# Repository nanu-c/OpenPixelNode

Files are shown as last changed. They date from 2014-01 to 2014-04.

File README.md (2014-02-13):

OpenPixelNode
=============

This project includes both hardware and software for an open-source LED controller for up to 4 ArtNet universes.

OpenPixelNode

More images here: http://flic.kr/s/aHsjQY2NrD

Hardware
--------
The hardware design is Arduino-compatible in terms of being based on an ATmega328 microcontroller running at 16MHz.
It uses the Wiznet Wiz820io addon board for Ethernet communication. There are voltage regulators for both 5V and 3.3V for the two logic circuits. This allows the board to be supplied with voltages of 5V to 30V.
There are 4 LED outputs with two digital ports each. This allows the board to control either SPI or single-wire LED strips.
At the moment there is only ICSP headers for programming.

Software
--------
The software is an Arduino sketch using a library for the ArtNet protocol and whatever LED communication protocol you may want to use. Please update the FastLED controller type to whatever LED you are using.

Dependencies
------------
[Arduino_ArtNet](https://github.com/media-architecture/Arduino_ArtNet)

[FastLED](https://github.com/media-architecture/FastLED)

[WIZ_Ethernet_Library](https://github.com/media-architecture/WIZ_Ethernet_Library)

[TrueRandom](https://code.google.com/p/tinkerit/wiki/TrueRandom)

Version history
---------------

### Prototype 2 (January 2014)
### Prototype 1 (September 2013)

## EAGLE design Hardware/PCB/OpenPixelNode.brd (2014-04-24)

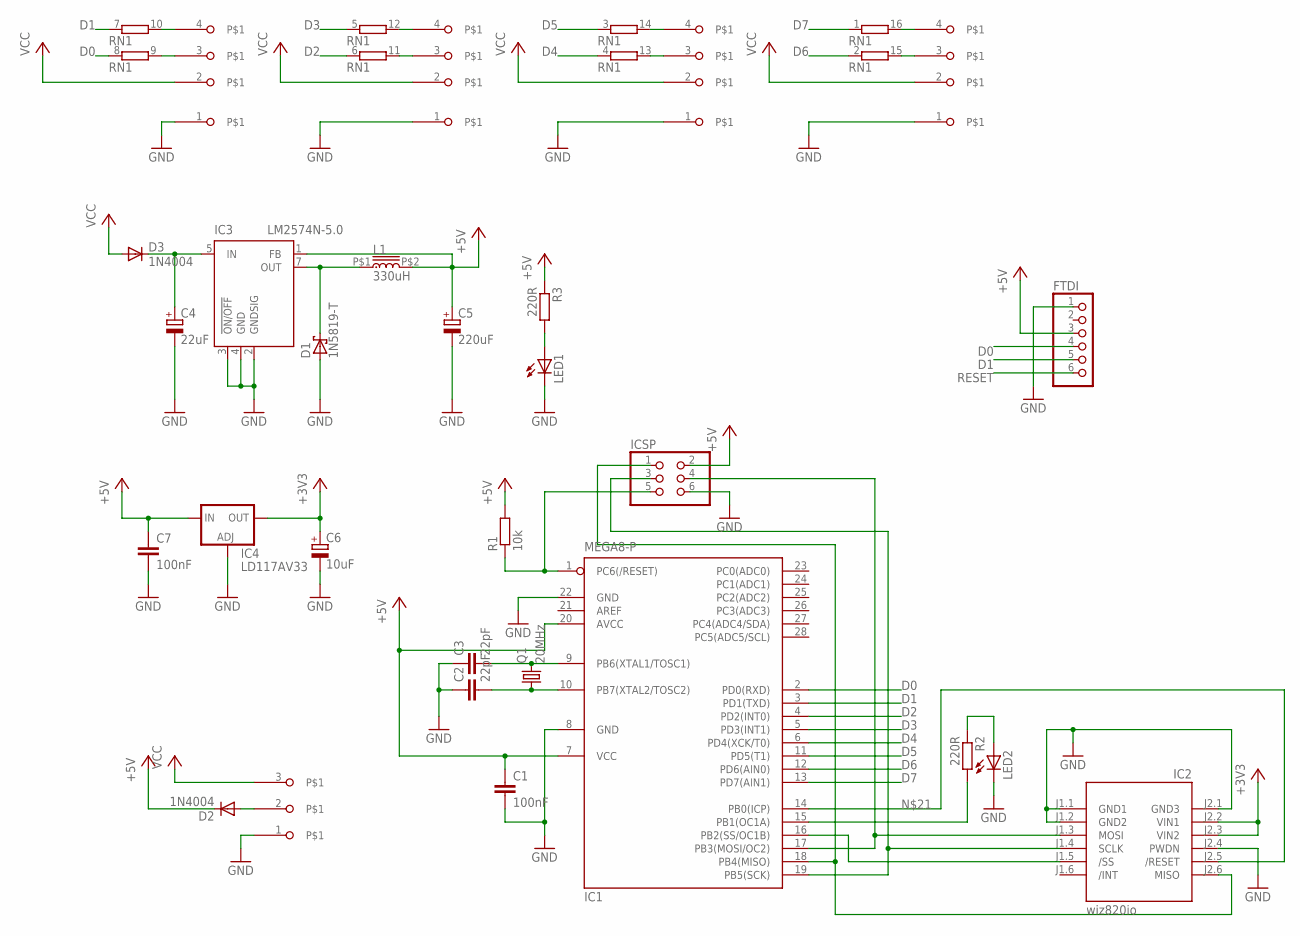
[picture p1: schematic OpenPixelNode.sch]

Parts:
C1, C7: 100nF; C025-025X050
C2, C3: 22pF; C025-025X050
C4: 22uF; E2,5-6
C5: 220uF; E2,5-6
C6: 10uF; E2,5-6
D1: 1N5819-T; DO41-7.6
D2, D3: 1N4004; DO41-10
FTDI: PINHD-1X6; 1X06
IC1: MEGA8-P; DIL28-3
IC2: wiz820io; WIZ820IO
IC3: LM2574N-5.0; DIL08
IC4: LD117AV33; TO220L1
ICSP: PINHD-2X3; 2X03
L1: 330uH; 13R334C
LED1, LED2: LED3MM
Q1: 20MHz; HC49/S
R1: 10k; 0207/10
R2, R3: 220R; 0207/10
RN1: 8R-P; DIL16
U$1, U$2, U$3, U$4: 691322110004
U$5: CTB9358/3

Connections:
+3V3: C6.+, IC2.J2.2 (VIN1), IC2.J2.3 (VIN2), IC4.2 (OUT)
+5V: C1.1, C5.+, C7.1, D2.C, FTDI.3, IC1.7 (VCC), IC1.20 (AVCC), IC3.1 (FB), IC4.3 (IN), ICSP.2, L1.P$2 (2), R1.2, R3.1; also elsewhere on the board
D0: FTDI.4, IC1.2 (PD0(RXD)), RN1.8 (1); also elsewhere on the board
D1: FTDI.5, IC1.3 (PD1(TXD)), RN1.7 (1); also elsewhere on the board
D2: IC1.4 (PD2(INT0)), RN1.6 (1)
D3: IC1.5 (PD3(INT1)), RN1.5 (1)
D4: IC1.6 (PD4(XCK/T0)), RN1.4 (1)
D5: IC1.11 (PD5(T1)), RN1.3 (1)
D6: IC1.12 (PD6(AIN0)), RN1.2 (1)
D7: IC1.13 (PD7(AIN1)), RN1.1
GND: C1.2, C2.1, C3.1, C4.-, C5.-, C6.-, C7.2, D1.A, FTDI.1, IC1.8 (GND), IC1.22 (GND), IC2.J1.1 (GND1), IC2.J1.2 (GND2), IC2.J2.1 (GND3), IC2.J2.4 (PWDN), IC3.2 (GNDSIG), IC3.3 (!ON/OFF), IC3.4 (GND), IC4.1 (ADJ), ICSP.6, LED1.K (C), LED2.K (C), U$1.1, U$2.1, U$3.1, U$4.1, U$5.1; also elsewhere on the board
unnamed: LED1.A, R3.2
unnamed: C3.2, IC1.9 (PB6(XTAL1/TOSC1)), Q1.2
unnamed: C2.2, IC1.10 (PB7(XTAL2/TOSC2)), Q1.1
unnamed: IC1.16 (PB2(SS/OC1B)), IC2.J1.5 (/SS)
unnamed: IC1.18 (PB4(MISO)), IC2.J2.6 (MISO), ICSP.1
unnamed: D2.A, U$5.2
unnamed: IC1.17 (PB3(MOSI/OC2)), IC2.J1.3 (MOSI), ICSP.4
unnamed: LED2.A, R2.1
unnamed: C4.+, D3.C, IC3.5 (IN)
unnamed: D1.C, IC3.7 (OUT), L1.P$1 (1)
unnamed: RN1.11 (2), U$2.3
unnamed: RN1.12 (2), U$2.4
unnamed: RN1.13 (2), U$3.3
unnamed: RN1.14 (2), U$3.4
unnamed: RN1.15 (2), U$4.3
unnamed: RN1.16 (2), U$4.4
unnamed: RN1.10 (2), U$1.4
unnamed: RN1.9 (2), U$1.3
unnamed: IC1.14 (PB0(ICP)), IC2.J2.5 (/RESET)
unnamed: IC1.15 (PB1(OC1A)), R2.2
RESET: FTDI.6, IC1.1 (PC6(/RESET)), ICSP.5, R1.1; also elsewhere on the board
SCK: IC1.19 (PB5(SCK)), IC2.J1.4 (SCLK), ICSP.3
VCC: D3.A, U$1.2, U$2.2, U$3.2, U$4.2, U$5.3

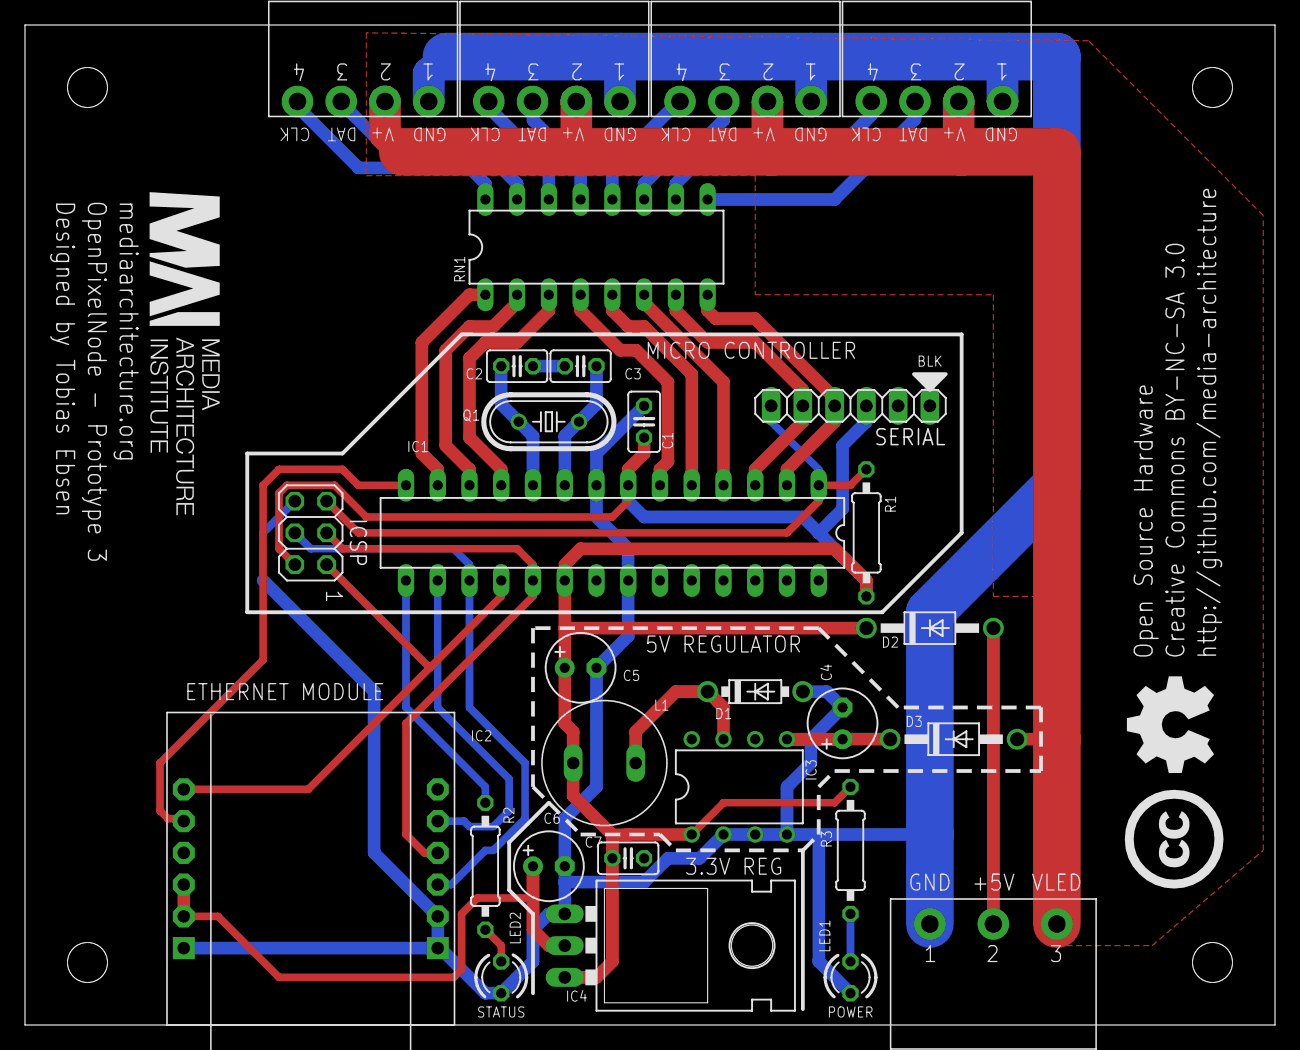
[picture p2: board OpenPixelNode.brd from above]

Board: 2 copper layers, 100.0 x 80.0 mm, 29 parts (0 on the bottom side), 34 nets.

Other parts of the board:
SERIAL: 1X06

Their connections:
+5V: SERIAL.3; also elsewhere on the board
D0: SERIAL.4; also elsewhere on the board
D1: SERIAL.5; also elsewhere on the board
GND: SERIAL.1; also elsewhere on the board
RESET: SERIAL.6; also elsewhere on the board

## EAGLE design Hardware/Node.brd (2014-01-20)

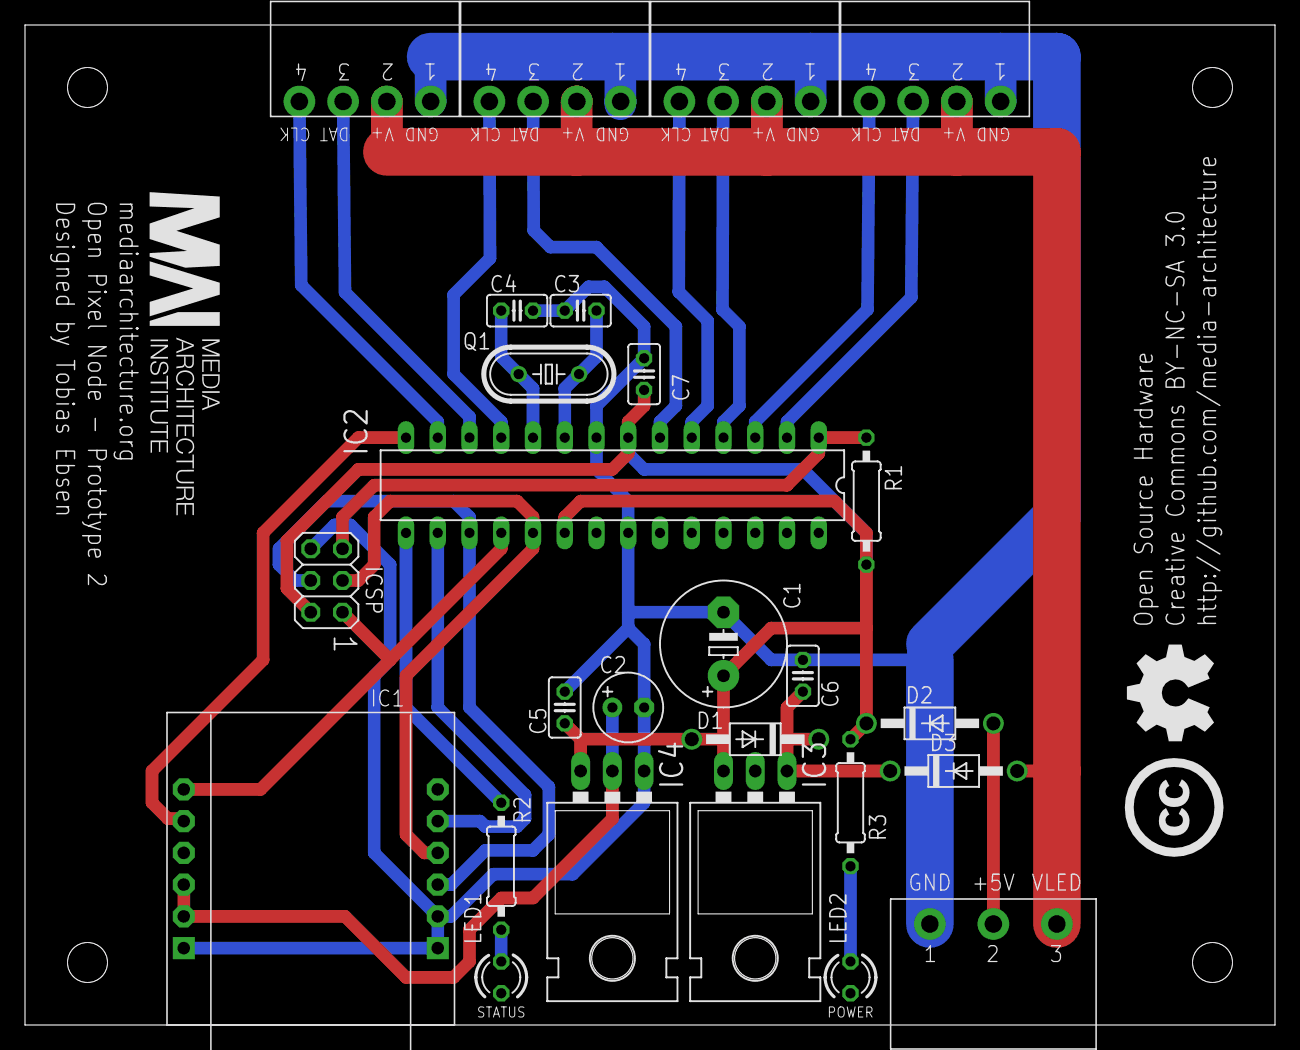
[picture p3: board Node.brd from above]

Board: 2 copper layers, 100.0 x 80.0 mm, 26 parts (0 on the bottom side), 25 nets.

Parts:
C1: E5-10,5
C2: E2,5-6
C3, C4: 22pF; C025-025X050
C5, C6: C025-025X050
C7: 100nF; C025-025X050
D1, D2, D3: 1N4004; DO41-10
IC1: wiz820io; WIZ820IO
IC2: MEGA8-P; DIL28-3
IC3: 78XXL
IC4: LD117AV33; TO220L1
ICSP: 2X03
LED1, LED2: LED3MM
Q1: 20MHz; HC49/S
R1: 10k; 0207/10
R2, R3: 0207/10
U$1, U$2, U$3, U$4: 691322110004
U$5: CTB9358/3

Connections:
+3V3: C2.+, IC1.J2.2, IC1.J2.3, IC4.2
+5V: C1.+, C5.1, C7.1, D1.A, D2.C, IC2.7, IC2.20, IC3.OUT, IC4.3, ICSP.2, R1.2, R3.1
D0: IC2.2, U$1.3
D1: IC2.3, U$1.4
D2: IC2.4, U$2.3
D3: IC2.5, U$2.4
D4: IC2.6, U$3.3
D5: IC2.11, U$3.4
D6: IC2.12, U$4.3
D7: IC2.13, U$4.4
GND: C1.-, C2.-, C3.1, C4.1, C5.2, C6.2, C7.2, IC1.J1.1, IC1.J1.2, IC1.J2.1, IC2.8, IC2.22, IC3.GND, IC4.1, ICSP.6, LED1.K, LED2.K, U$1.1, U$2.1, U$3.1, U$4.1, U$5.1
unnamed: LED2.A, R3.2
unnamed: C3.2, IC2.9, Q1.2
unnamed: C4.2, IC2.10, Q1.1
unnamed: IC1.J1.5, IC2.16
unnamed: IC1.J2.6, IC2.18, ICSP.1
unnamed: D2.A, U$5.2
unnamed: IC1.J1.3, IC2.17, ICSP.4
unnamed: LED1.A, R2.1
unnamed: C6.1, D1.C, D3.C, IC3.IN
unnamed: IC1.J2.5, IC2.14
unnamed: IC2.15, R2.2
RESET: IC2.1, ICSP.5, R1.1
SCK: IC1.J1.4, IC2.19, ICSP.3
VCC: D3.A, U$1.2, U$2.2, U$3.2, U$4.2, U$5.3

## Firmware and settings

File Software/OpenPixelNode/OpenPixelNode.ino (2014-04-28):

/*
 * OpenPixelNode - Version 0.21
 * by Media Architecture Institute
 *
 * https://github.com/media-architecture/OpenPixelNode
 *
 * Author: Tobias Ebsen
 * 
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
 */

#include <avr/wdt.h>
#include <SPI.h>
#include <Ethernet.h>   // https://github.com/media-architecture/WIZ_Ethernet_Library
#include <ArtNet.h>     // https://github.com/media-architecture/Arduino_ArtNet/
#include <TrueRandom.h> // https://code.google.com/p/tinkerit/wiki/TrueRandom
#include <FastLED.h>    // https://github.com/FastLED/FastLED

#define LED_PIN  9

// Firmware version
#define OPN_VERSION_HIGH 0
#define OPN_VERSION_LOW  22

// Default Configuration
ArtNetConfig config = {
  {0xDE, 0xAD, 0xBE, 0xEF, 0xFE, 0xED}, // MAC
  {192, 168, 1, 1},                     // IP
  {255, 255, 255, 0},                   // Subnet mask
  0x1936,                               // UDP port
  true,                                 // DHCP
  0, 0,                                 // Net and subnet
  "OpenPixelNode",                      // Short name
  "OpenPixelNode by Media Architecture Institute", // Long name
  4,                                    // Number of ports
  {ARTNET_TYPE_DMX|ARTNET_TYPE_OUTPUT,ARTNET_TYPE_DMX|ARTNET_TYPE_OUTPUT,ARTNET_TYPE_DMX|ARTNET_TYPE_OUTPUT,ARTNET_TYPE_DMX|ARTNET_TYPE_OUTPUT}, // Port types
  {0, 1, 2, 3},                         // Input port addresses
  {0, 1, 2, 3}                          // Output port addresses
};

ArtNet artnet = ArtNet(config, 530);

// LED control
static WS2811Controller800Khz<0, GRB> port1;
static WS2811Controller800Khz<2, GRB> port2;
static WS2811Controller800Khz<4, GRB> port3;
static WS2811Controller800Khz<6, GRB> port4;

void setup() {
  
  pinMode(LED_PIN, OUTPUT);
  digitalWrite(LED_PIN, HIGH);
  
  // Initialization and optimization
  ethernetInit();
  
  // Read config from EEPROM
  configGet(config);
  config.verHi = OPN_VERSION_HIGH;
  config.verLo = OPN_VERSION_LOW;

  // Initialize FastLED
  port1.init();
  port2.init();
  port3.init();
  port4.init();

  // Start ArtNet
  artnet.begin();
  
  ethernetMaximize();
  
  wdt_enable(WDTO_2S);

  digitalWrite(LED_PIN, LOW);
}

void loop() {
  
  if(artnet.parsePacket() > 0) {
    
    digitalWrite(LED_PIN, HIGH);

    switch(artnet.getOpCode()) {
      
      case ARTNET_OPCODE_DMX: {
          switch(artnet.getDmxPort()) {
            case 0: port1.show((CRGB*)artnet.getDmxData(), artnet.getDmxLength() / 3);break;
            case 1: port2.show((CRGB*)artnet.getDmxData(), artnet.getDmxLength() / 3);break;
            case 2: port3.show((CRGB*)artnet.getDmxData(), artnet.getDmxLength() / 3);break;
            case 3: port4.show((CRGB*)artnet.getDmxData(), artnet.getDmxLength() / 3);break;
          }
      } break;
      
      case ARTNET_OPCODE_IPPROG:
        artnet.handleIpProg();
        configWrite(config);
        break;
        
      case ARTNET_OPCODE_ADDRESS:
        artnet.handleAddress();
        configWrite(config);
        break;
      
      default:
        artnet.handleAny();
    }
    digitalWrite(LED_PIN, LOW);
  }
  // Check DHCP lease
  if(config.dhcp)
    artnet.maintain();
  
  wdt_reset();
}

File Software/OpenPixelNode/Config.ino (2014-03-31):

#include <EEPROM.h>
#include <TrueRandom.h>

static char EEPROM_MAGIC[] = "OPN ";

void configGet(ArtNetConfig & config) {
  if(configCheckMagic()) {
    configRead(config);
  }
  else {
    TrueRandom.mac(config.mac);
    configWriteMagic();
    configWrite(config);
  }
}

boolean configCheckMagic() {
  for(int i=0; i<4; i++) {
    if(EEPROM.read(i) != EEPROM_MAGIC[i])
      return false;
  }
  return true;
}

void configWriteMagic() {
  for(int i=0; i<4; i++)
    EEPROM.write(i, EEPROM_MAGIC[i]);
}

void configRead(ArtNetConfig & config) {
  byte *data = (byte*)&config;
  for(int i=0; i<sizeof(ArtNetConfig); i++)
    data[i] = EEPROM.read(4+i);
}

void configWrite(ArtNetConfig & config) {
  byte *data = (byte*)&config;
  for(int i=0; i<sizeof(ArtNetConfig); i++)
    EEPROM.write(4+i, data[i]);
}

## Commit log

2014-01-20 Updated hardware for prototype 2
    [Node.brd, Node.sch]
2014-02-14 Fixed missing init on FastLED
    [OpenPixelNode.ino]
2014-02-14 Fixed number of pixels error
    [OpenPixelNode.ino]
2014-03-19 Bugfixes and updates for DHCP
    [Config.ino, OpenPixelNode.ino]
2014-04-24 Updated hardware to Prototype 3
    [Node.sch, OpenPixelNode.brd, OpenPixelNode.sch]
2014-04-28 Bugfixes and added watchdog timer
    [Ethernet.ino, OpenPixelNode.ino]

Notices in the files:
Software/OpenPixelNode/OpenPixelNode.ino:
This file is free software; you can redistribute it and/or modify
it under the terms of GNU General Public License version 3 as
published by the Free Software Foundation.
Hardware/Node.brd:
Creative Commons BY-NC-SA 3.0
